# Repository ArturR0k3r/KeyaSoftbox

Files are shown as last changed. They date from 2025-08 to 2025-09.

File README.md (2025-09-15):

# KSB (Keya-Soft-Box) - Mesh LED Lighting System




[]()

A self-organizing mesh network LED lighting system built on ESP32 microcontrollers running Zephyr RTOS. KSB enables multiple LED lamps to automatically discover and connect to each other, creating synchronized lighting effects across an entire network.

KSB Hardware

## 🌟 Features

- **🔗 Automatic Mesh Networking**: Devices self-discover and form mesh networks
- **🎨 Synchronized LED Control**: Coordinated lighting effects across all connected devices
- **📱 Web Configuration**: Simple browser-based setup interface
- **🔋 Battery Monitoring**: Built-in power management and monitoring
- **🛡️ Self-Healing Network**: Automatic recovery from node failures  
- **⚡ Real-time RTOS**: Built on Zephyr RTOS for reliable operation
- **🎯 Multiple Board Support**: ESP32-S3, ESP32-C3, and XIAO variants

## 🚀 Quick Start

### Prerequisites

1. **Install Zephyr SDK**:
   ```bash
   cd your-workspace
   west init -m https://github.com/zephyrproject-rtos/zephyr --mr v3.4.0
   west update
   west blobs fetch hal_espressif
   ```

2. **Install ESP Tool**:
   ```bash
   pip3 install --user --upgrade esptool>=5.0.2 --break-system-packages
   export PATH=$HOME/.local/bin:$PATH
   ```

### Clone & Build

```bash
git clone https://github.com/your-org/keya-soft-box.git
cd keya-soft-box

# Build for ESP32-S3-DevKitM (default)
west build -b esp32s3_devkitm

# Or build for other supported boards:
# west build -b esp32c3_devkitm
# west build -b xiao_esp32c3

# Flash the firmware
west flash

# Monitor serial output
west build -t monitor
```

## 🔌 Hardware

### Supported Boards
- **ESP32-S3-DevKitM** - Primary development platform
### Soon Will Be
- **ESP32-C3-DevKitM** - Compact alternative
- **XIAO ESP32C3** - Ultra-small form factor

### Hardware Features
- **ESP32-S3/C3** microcontroller with WiFi
- **8x WS2812B** addressable LEDs
- **User button** with debouncing
- **Dual status LEDs** (Red/Green)
- **Battery monitoring** via ADC
- **Debug interface** (UART + SWD)
- **Power regulation** and filtering

### Pin Configuration
```
LED Strip:    GPIO11 (SPI2 MOSI) 
User Button:  GPIO0 (Pull-up, Active Low)
Status LEDs:  Red/Green with 220Ω resistors
Debug UART:   TX=GPIO43, RX=GPIO44
Power:        3.3V regulated with monitoring
```

## 📊 System Architecture

### Mesh Network States
```mermaid
stateDiagram-v2
    [*] --> SYSTEM_INIT
    SYSTEM_INIT --> CONFIG_MODE : Hardware Ready
    CONFIG_MODE --> NETWORK_SCAN : User Config Done
    NETWORK_SCAN --> MESH_CLIENT : Network Found
    NETWORK_SCAN --> MESH_MASTER : No Network Found
    MESH_CLIENT --> OPERATIONAL : Connected to Mesh
    MESH_MASTER --> OPERATIONAL : Mesh Created
    OPERATIONAL --> CONNECTION_LOST : Network Failure
    CONNECTION_LOST --> ERROR_RECOVERY : Start Recovery
    ERROR_RECOVERY --> CONFIG_MODE : Recovery Failed
    ERROR_RECOVERY --> NETWORK_SCAN : Retry Connection
```

### Key Components
- **Mesh Networking**: Self-organizing WiFi mesh with automatic node discovery
- **LED Control**: Synchronized WS2812B patterns across all network nodes  
- **Web Interface**: Browser-based configuration at `192.168.4.1` during setup
- **State Machine**: Robust state management with error recovery
- **NVS Storage**: Persistent configuration storage

## ⚙️ Configuration

### Device Tree Setup
The project includes board-specific overlays:

```c
// WS2812B LED strip configuration
&spi2 {
    led_strip: ws2812@0 {
        compatible = "worldsemi,ws2812-spi";
        chain-length = <8>;
        spi-max-frequency = <4000000>;
        color-mapping = <LED_COLOR_ID_GREEN>,
                        <LED_COLOR_ID_RED>, 
                        <LED_COLOR_ID_BLUE>;
    };
};
```

### Kconfig Options
Key configuration options in `prj.conf`:
```
CONFIG_WS2812B_STRIP=y
CONFIG_WS2812B_MAX_PIXELS=256
CONFIG_NETWORKING=y
CONFIG_WIFI=y
CONFIG_HTTP_SERVER=y
CONFIG_NVS=y
```

## 🎮 Usage

### Initial Setup
1. **Power on** the device - it creates a WiFi access point `KSB_Setup_XXXX`
2. **Connect** to the AP and navigate to `192.168.4.1`
3. **Configure** your mesh network name (e.g., "Living Room")
4. **Save** configuration - device will restart and search for existing networks

### Network Formation
- **First device**: Creates new mesh network as root node
- **Additional devices**: Automatically discover and join existing mesh
- **Status indication**: LEDs show current state (scanning, connecting, operational)

### LED Control
- **Synchronized patterns** across all connected devices
- **Button control** for basic pattern switching
- **Web interface** for advanced pattern configuration
- **Mesh broadcast** ensures all nodes stay synchronized

## 🛠️ Development

### Project Structure
```
keya-soft-box/
├── boards/                 # Board-specific overlays
├── dts/                    # Device tree sources
├── Housing/                # Housing 3d models for print 
├── include/                # Version include
├── modules/                # modules.cmake
├── src/                    # Application source
│   ├── main.c             # Main application
│   ├── mesh_network.c     # Mesh networking logic
│   ├── led_control.c      # LED pattern control
│   └── web_config.c       # Web configuration
├── Wiring/                 # Schematic for KSB
├── ws2812/                 # WS2812 custom driver 
├── CMakeLists.txt          # Build configuration
├── Kconfig                 # Config options
├── KSB.code-workspace      # VS-code workspace
├── LICENSE                 # License file
├── prj.conf                # Project config
├── README.md               # this doc
└── west.yml                # file for west update
```

### Building for Different Boards

```bash
# ESP32-S3-DevKitM (recommended)
west build -b esp32s3_devkitm

# ESP32-C3-DevKitM  
west build -b esp32c3_devkitm

# XIAO ESP32C3
west build -b xiao_esp32c3
```

### Custom LED Patterns
Add new patterns in `src/led_control.c`:
```c
void pattern_custom(struct led_rgb *leds, uint32_t frame) {
    // Your custom pattern implementation
    for (int i = 0; i < LED_STRIP_LENGTH; i++) {
        leds[i] = (struct led_rgb){
            .r = /* red value */,
            .g = /* green value */,
            .b = /* blue value */
        };
    }
}
```

## 🧪 Testing

### Hardware Testing
- [ ] Power supply regulation (3.3V ±5%)
- [ ] All 8 WS2812B LEDs functional
- [ ] Button input with proper debouncing
- [ ] UART debug communication
- [ ] WiFi connectivity and range

### Software Testing  
- [ ] State machine transitions
- [ ] Mesh network formation (2-8 nodes)
- [ ] LED pattern synchronization
- [ ] Network recovery after node failure
- [ ] Configuration persistence

### Performance Targets
- **Mesh formation**: < 60 seconds for 8 nodes
- **LED update rate**: 30 FPS
- **Network recovery**: < 10 seconds  
- **Power consumption**: < 500mA @ 3.3V per node
- **Range**: 10-30m indoor, 50-100m outdoor

## 🐛 Troubleshooting

### Common Issues

**Build Errors**
```bash
# Ensure Zephyr SDK is properly installed
west --version
which esptool.py

# Clean and rebuild
west build -t clean
west build
```

**Flash Errors**
```bash
# Check USB connection and permissions
ls -la /dev/ttyUSB* /dev/ttyACM*

# Try different baud rate
west flash --baud 115200
```

**WiFi Connection Issues**
- Check antenna connection
- Verify 2.4GHz WiFi support
- Ensure regulatory domain settings
- Test in different locations for interference

**LED Problems**  
- Verify 3.3V power supply stability
- Check WS2812B data line continuity
- Ensure proper GND connection
- Test with simple solid color first

### Debug Output
Enable detailed logging in `prj.conf`:
```
CONFIG_LOG=y
CONFIG_LOG_DEFAULT_LEVEL=4
CONFIG_MESH_NETWORK_LOG_LEVEL_DBG=y
```

## 📚 API Documentation

### Mesh Network API
```c
// Initialize mesh networking
int mesh_network_init(const char *network_name);

// Join or create mesh network
int mesh_network_start(void);

// Send LED command to all nodes
int mesh_broadcast_led_command(struct led_command *cmd);
```

### LED Control API
```c
// Set LED pattern for entire strip
int led_set_pattern(enum led_pattern pattern, struct led_rgb color);

// Update single LED
int led_set_pixel(int index, struct led_rgb color);

// Apply changes to physical LEDs
int led_update_strip(void);
```

## 🤝 Contributing

We welcome contributions! Please see our [Contributing Guide](CONTRIBUTING.md) for details.

### Development Workflow
1. **Fork** the repository
2. **Create** a feature branch (`git checkout -b feature/amazing-feature`)
3. **Commit** your changes (`git commit -m 'Add amazing feature'`)
4. **Push** to the branch (`git push origin feature/amazing-feature`)
5. **Open** a Pull Request

### Code Style
- Follow Zephyr coding conventions
- Use descriptive variable and function names
- Add comments for complex algorithms
- Include unit tests for new features

## 📋 Versions

### Version 1.1 (Done)
- [ ] Web interface for remote control
- [ ] Advanced LED patterns and effects
- [ ] Energy-saving sleep modes
- [ ] Over-the-air (OTA) firmware updates

## 📄 License

This project is licensed under the MIT License - see the [LICENSE](LICENSE) file for details.

## 🙏 Acknowledgments

- **Zephyr Project** - For the excellent RTOS foundation
- **Espressif** - For ESP32 hardware and support
- **WS2812B Community** - For LED strip driver inspiration
- **Contributors** - Everyone who helps improve this project

## 📞 Support

- **Issues**: Report bugs and request features on [GitHub Issues](https://github.com/ArturR0k3r/KeyaSoftbox/issues)
- **Email**: Contact the maintainers at artur@pen.engineering

---

**⭐ Star this repo if you find it useful!**

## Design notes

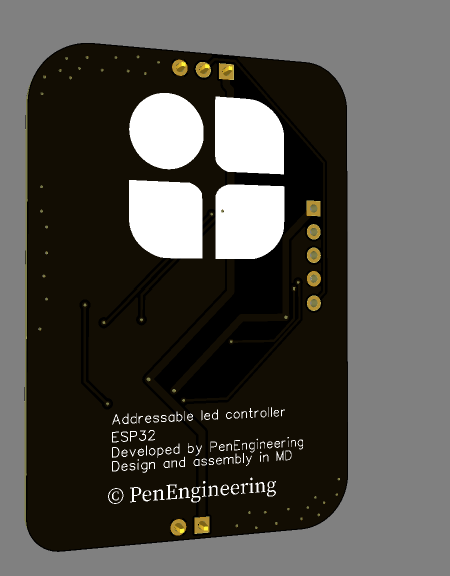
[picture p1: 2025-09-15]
Hardware/Screenshot 2025-09-14 190648.png

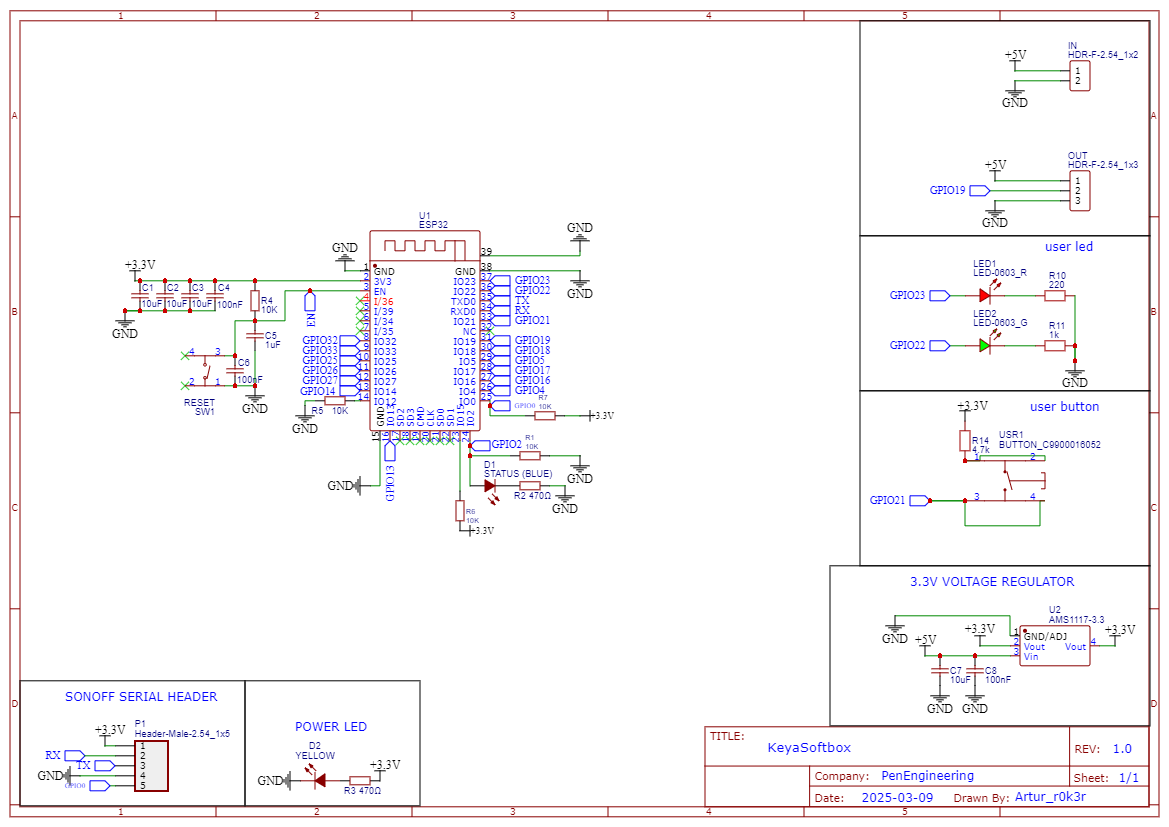
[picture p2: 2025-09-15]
Hardware/Schematic_KeyaSoftbox_2025-09-14.png

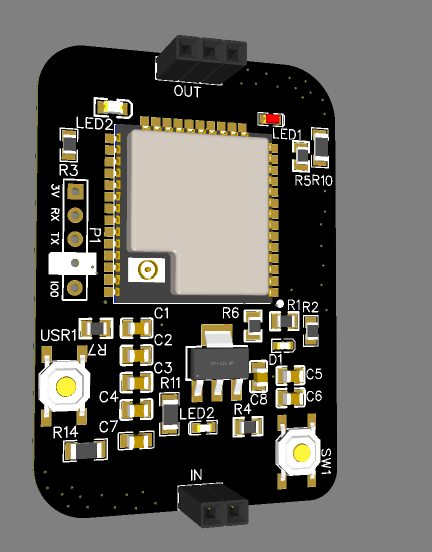
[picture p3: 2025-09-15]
Hardware/Screenshot 2025-09-14 190716.png

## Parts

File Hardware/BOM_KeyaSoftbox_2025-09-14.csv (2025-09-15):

ID | Name | Designator | Footprint | Quantity | Manufacturer Part | Manufacturer | Supplier | Supplier Part | Price
1 | YELLOW | D2 | LED0805-RD | 1 | 17-21SUYC/TR8 | KENTO | LCSC | C2296 | 0.012
2 | LED-0603_G | LED2 | LED0603_GREEN | 1 | 19-217/GHC-YR1S2/3T | EVERLIGHT(台湾亿光) | LCSC | C72043 | 0.022
3 | STATUS (BLUE) | D1 | LED0603-R-RD | 1 | 19-217/BHC-ZL1M2RY/3T | EVERLIGHT | LCSC | C72041 | 0.023
4 | LED-0603_R | LED1 | LED0603_RED | 1 | 19-217/R6C-AL1M2VY/3T | EVERLIGHT(台湾亿光) | LCSC | C72044 | 0.021
5 | 10uF | C1,C2,C3,C7 | C0805 | 4 | CL21A106KAYNNNE | SAMSUNG | LCSC | C15850 | 0.011
6 | 100nF | C4,C6,C8 | C0805 | 3 | CC0805KRX7R9BB104 | YAGEO | LCSC | C49678 | 0.005
7 | 1uF | C5 | C0805 | 1 | CL21B105KBFNNNE | SAMSUNG | LCSC | C28323 | 0.009
8 | HDR-F-2.54_1x2 | IN | HDR-F-2.54_1X2 | 1 |  |  | LCSC | C49661 | 0.038
9 | HDR-F-2.54_1x3 | OUT | HDR-F-2.54_1X3 | 1 |  |  | LCSC | C146690 | 0.087
10 | Header-Male-2.54_1x5 | P1 | HDR-5X1/2.54 | 1 | Header-Male-2.54_1x5 | LCSC
11 | 10K | R1,R4,R5,R6,R7 | R0805 | 5 | 0805W8F1002T5E | UniOhm | LCSC | C17414 | 0.002
12 | 470Ω | R2,R3 | R0805 | 2 | 0805W8F4700T5E | UniOhm | LCSC | C17710 | 0.002
13 | 220 | R10 | R1206 | 1
14 | 1k | R11 | R1206 | 1
15 | 4.7k | R14 | R1206 | 1
16 | RESET | SW1 | SW-SMD_4P-L5.1-W5.1-P3.70-LS6.5-TL-2 | 1 | TS-1187A-B-A-B | XKB Enterprise | LCSC | C318884 | 0.019
17 | ESP32 | U1 | WIFIM-SMD_38P-L19.2-W18.0-P1.27 | 1 | ESP32 |  | LCSC | C328062 | 3.523
18 | AMS1117-3.3 | U2 | SOT-223-3_L6.5-W3.4-P2.30-LS7.0-BR | 1 | AMS1117-3.3 | AMS | LCSC | C6186 | 0.167
19 | BUTTON_C9900016052 | USR1 | SW-SMD_4P-L5.1-W5.1-P3.70-LS6.5-TL-2 | 1 | button | null | LCSC | C9900016052

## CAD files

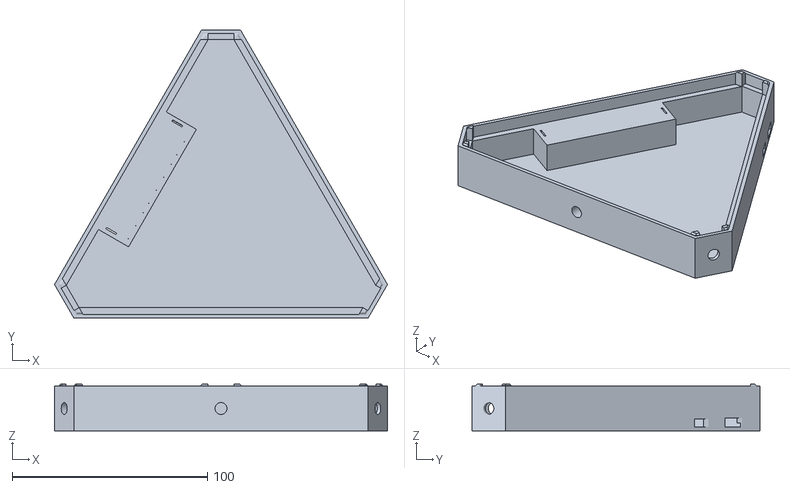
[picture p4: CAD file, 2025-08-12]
Housing/KSB_Body.stl
170.6 x 147.7 x 24.0

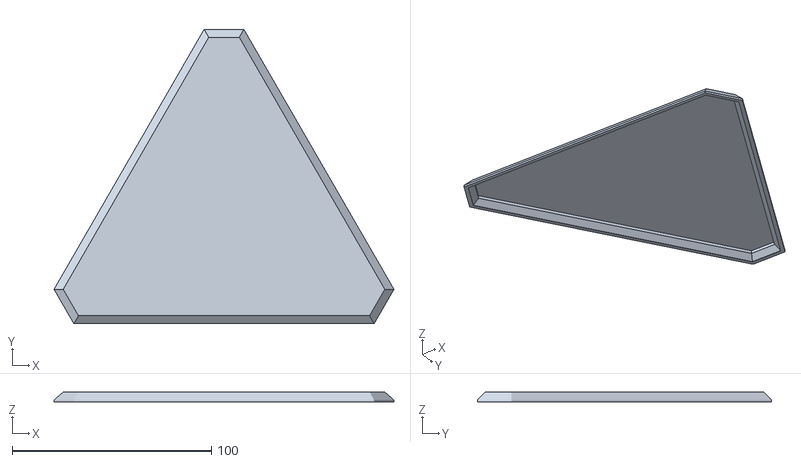
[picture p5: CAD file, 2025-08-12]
Housing/KSB_Top.stl
170.6 x 147.7 x 5.00

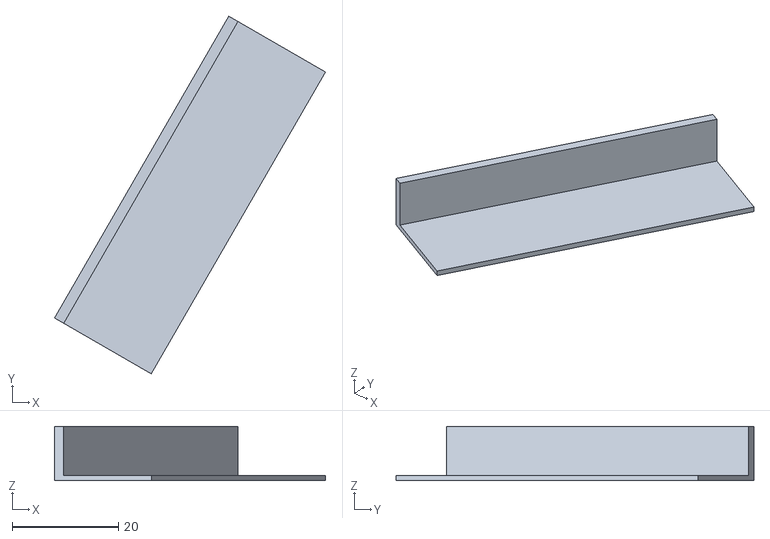
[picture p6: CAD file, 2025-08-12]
Housing/KSB_BatLid.stl
50.9 x 67.2 x 10.2

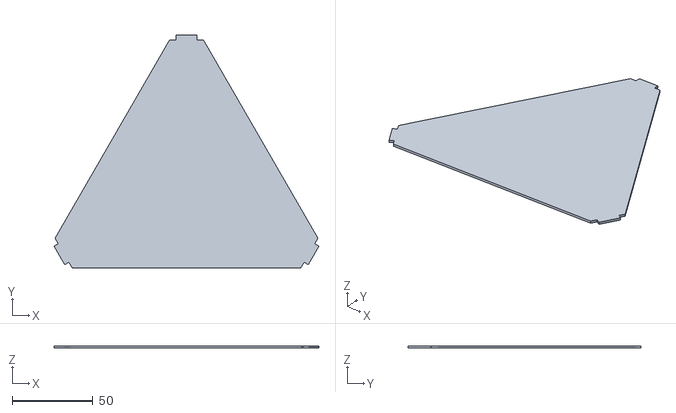
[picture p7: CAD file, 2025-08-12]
Housing/KSB_LED_Holder.stl
163.8 x 143.7 x 1.40

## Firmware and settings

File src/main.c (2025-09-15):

#include <zephyr/kernel.h>
#include <zephyr/device.h>
#include <zephyr/drivers/gpio.h>
#include <zephyr/logging/log.h>
#include <zephyr/random/random.h>

#include "ksb_common.h"
#include "state_machine.h"
#include "nvs_storage.h"
#include "../ws2812/ws2812_driver.h"

LOG_MODULE_REGISTER(main, CONFIG_LOG_DEFAULT_LEVEL);

// Global system context
struct ksb_context g_ksb_ctx = {
    .current_state = KSB_STATE_SYSTEM_INIT,
    .system_running = true};

// Hardware devices
static const struct device *button_dev;
static const struct device *status_red_dev;
static const struct device *status_green_dev;
static const struct device *gpio_dev;
static struct gpio_callback button_cb_data;

// Button handler
static void button_pressed(const struct device *dev, struct gpio_callback *cb, uint32_t pins)
{
    LOG_INF("User button pressed");
    // Cycle through LED patterns in operational mode
    if (g_ksb_ctx.current_state == KSB_STATE_OPERATIONAL)
    {
        led_control_next_pattern();
    }
}

// Status LED control
static void set_status_leds(bool red, bool green)
{
    if (gpio_dev)
    {
        gpio_pin_set(gpio_dev, 23, red ? 1 : 0);   // user_led1
        gpio_pin_set(gpio_dev, 22, green ? 1 : 0); // user_led2
    }
}

// Status LED thread
static void status_led_thread(void)
{
    while (g_ksb_ctx.system_running)
    {
        switch (g_ksb_ctx.current_state)
        {
        case KSB_STATE_SYSTEM_INIT:
            // Fast red blink during init
            set_status_leds(true, false);
            k_msleep(100);
            set_status_leds(false, false);
            k_msleep(100);
            break;

        case KSB_STATE_CONFIG_MODE:
            // Alternating red/green in config mode
            set_status_leds(true, false);
            k_msleep(500);
            set_status_leds(false, true);
            k_msleep(500);
            break;

        case KSB_STATE_NETWORK_SCAN:
        case KSB_STATE_MESH_CLIENT:
        case KSB_STATE_MESH_MASTER:
            // Slow green blink during connection
            set_status_leds(false, true);
            k_msleep(250);
            set_status_leds(false, false);
            k_msleep(1750);
            break;

        case KSB_STATE_OPERATIONAL:
            // Solid green when operational
            set_status_leds(false, true);
            k_msleep(1000);
            break;

        case KSB_STATE_CONNECTION_LOST:
        case KSB_STATE_ERROR_RECOVERY:
            // Fast red blink on error
            set_status_leds(true, false);
            k_msleep(200);
            set_status_leds(false, false);
            k_msleep(200);
            break;

        default:
            set_status_leds(false, false);
            k_msleep(1000);
            break;
        }
    }
}

K_THREAD_DEFINE(status_led_tid, 1024, status_led_thread, NULL, NULL, NULL, 7, 0, 0);

// Hardware initialization
static int init_hardware(void)
{
    int ret;

    // Get GPIO device for button and LEDs
    gpio_dev = DEVICE_DT_GET(DT_NODELABEL(gpio0));
    if (!device_is_ready(gpio_dev))
    {
        LOG_ERR("GPIO device not ready");
        return -ENODEV;
    }

    // Configure button pin
    ret = gpio_pin_configure(gpio_dev, 21, GPIO_INPUT | GPIO_PULL_UP);
    if (ret != 0)
    {
        LOG_ERR("Failed to configure button pin");
        return ret;
    }

    ret = gpio_pin_interrupt_configure(gpio_dev, 21, GPIO_INT_EDGE_TO_ACTIVE);
    if (ret != 0)
    {
        LOG_ERR("Failed to configure button interrupt");
        return ret;
    }

    gpio_init_callback(&button_cb_data, button_pressed, BIT(21));
    gpio_add_callback(gpio_dev, &button_cb_data);

    // Configure status LED pins
    ret = gpio_pin_configure(gpio_dev, 23, GPIO_OUTPUT_INACTIVE); // user_led1
    if (ret != 0)
    {
        LOG_ERR("Failed to configure red LED pin");
        return ret;
    }
    ret = gpio_pin_configure(gpio_dev, 22, GPIO_OUTPUT_INACTIVE); // user_led2
    if (ret != 0)
    {
        LOG_ERR("Failed to configure green LED pin");
        return ret;
    }

    LOG_INF("Hardware initialized successfully");
    return 0;
}

int main(void)
{
    int ret;

    LOG_INF("KSB v%s starting...", KSB_VERSION_STRING);
    LOG_INF("Build: %s %s", KSB_BUILD_DATE, KSB_BUILD_TIME);

    // Initialize semaphores
    k_sem_init(&g_ksb_ctx.state_lock, 1, 1);

    // Initialize NVS storage
    ret = nvs_storage_init();
    if (ret != 0)
    {
        LOG_ERR("Failed to initialize NVS storage: %d", ret);
        return ret;
    }

    // Load configuration
    ret = nvs_storage_load_config(&g_ksb_ctx.config);
    if (ret != 0)
    {
        LOG_WRN("No valid configuration found, using defaults");
        memset(&g_ksb_ctx.config, 0, sizeof(g_ksb_ctx.config));
        g_ksb_ctx.config.is_configured = false;
        g_ksb_ctx.config.device_id = sys_rand32_get() & 0xFF;
    }

    // Initialize hardware
    ret = init_hardware();
    if (ret != 0)
    {
        LOG_ERR("Hardware initialization failed: %d", ret);
        return ret;
    }

    // Initialize LED control
    ret = led_control_init();
    if (ret != 0)
    {
        LOG_ERR("LED control initialization failed: %d", ret);
        return ret;
    }

    // Show startup pattern
    struct led_rgb startup_color = {50, 0, 50}; // Purple
    led_control_set_pattern(KSB_PATTERN_SOLID, startup_color, 255, 0);
    k_msleep(1000);
    led_control_set_pattern(KSB_PATTERN_OFF, (struct led_rgb){0, 0, 0}, 0, 0);

    // Initialize state machine
    ret = state_machine_init();
    if (ret != 0)
    {
        LOG_ERR("State machine initialization failed: %d", ret);
        return ret;
    }

    LOG_INF("KSB initialization complete");

    // Start state machine
    state_machine_start();

    return 0;
}

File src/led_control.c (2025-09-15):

#include <zephyr/kernel.h>
#include <zephyr/logging/log.h>
#include <zephyr/random/random.h>

#include <math.h>
#include "ksb_common.h"
#include "led_control.h"
#include "mesh_network.h"
#include "../ws2812/ws2812_driver.h"

LOG_MODULE_REGISTER(led_control, CONFIG_LOG_DEFAULT_LEVEL);

static struct led_control_context
{
    struct ws2812_driver ws_driver;
    enum ksb_led_pattern current_pattern;
    struct led_rgb current_color;
    uint32_t current_brightness;
    uint32_t current_speed;
    uint32_t frame_counter;
    bool running;
    struct k_thread led_thread;
    K_KERNEL_STACK_MEMBER(led_stack, 2048);
} led_ctx;

// Pattern implementations
static void pattern_off(struct led_rgb *leds, uint32_t frame)
{
    struct led_rgb black = {0, 0, 0};
    for (int i = 0; i < KSB_LED_COUNT; i++)
    {
        leds[i] = black;
    }
}

static void pattern_solid(struct led_rgb *leds, uint32_t frame)
{
    for (int i = 0; i < KSB_LED_COUNT; i++)
    {
        leds[i] = led_ctx.current_color;
    }
}

static void pattern_breathing(struct led_rgb *leds, uint32_t frame)
{
    // Sine wave breathing effect
    float breath = (sin((frame * led_ctx.current_speed) / 1000.0f) + 1.0f) / 2.0f;
    uint8_t brightness = (uint8_t)(breath * led_ctx.current_brightness);

    struct led_rgb color = {
        (led_ctx.current_color.r * brightness) / 255,
        (led_ctx.current_color.g * brightness) / 255,
        (led_ctx.current_color.b * brightness) / 255};

    for (int i = 0; i < KSB_LED_COUNT; i++)
    {
        leds[i] = color;
    }
}

static void pattern_running_light(struct led_rgb *leds, uint32_t frame)
{
    // Clear all LEDs
    struct led_rgb black = {0, 0, 0};
    for (int i = 0; i < KSB_LED_COUNT; i++)
    {
        leds[i] = black;
    }

    // Calculate position
    int pos = (frame * led_ctx.current_speed / 100) % KSB_LED_COUNT;
    leds[pos] = led_ctx.current_color;

    // Add trail
    int trail_pos = (pos - 1 + KSB_LED_COUNT) % KSB_LED_COUNT;
    leds[trail_pos] = (struct led_rgb){
        led_ctx.current_color.r / 3,
        led_ctx.current_color.g / 3,
        led_ctx.current_color.b / 3};
}

static void pattern_rainbow(struct led_rgb *leds, uint32_t frame)
{
    for (int i = 0; i < KSB_LED_COUNT; i++)
    {
        float hue = ((frame * led_ctx.current_speed / 10) + (i * 360 / KSB_LED_COUNT)) % 360;

        // Simple HSV to RGB conversion
        float c = (float)led_ctx.current_brightness / 255.0f;
        float x = c * (1 - fabs(fmod(hue / 60.0f, 2) - 1));
        float m = 0;

        float r, g, b;
        if (hue < 60)
        {
            r = c;
            g = x;
            b = 0;
        }
        else if (hue < 120)
        {
            r = x;
            g = c;
            b = 0;
        }
        else if (hue < 180)
        {
            r = 0;
            g = c;
            b = x;
        }
        else if (hue < 240)
        {
            r = 0;
            g = x;
            b = c;
        }
        else if (hue < 300)
        {
            r = x;
            g = 0;
            b = c;
        }
        else
        {
            r = c;
            g = 0;
            b = x;
        }

        leds[i] = (struct led_rgb){
            (uint8_t)((r + m) * 255),
            (uint8_t)((g + m) * 255),
            (uint8_t)((b + m) * 255)};
    }
}

static void pattern_sparkle(struct led_rgb *leds, uint32_t frame)
{
    // Start with dim background
    struct led_rgb dim_color = {
        led_ctx.current_color.r / 10,
        led_ctx.current_color.g / 10,
        led_ctx.current_color.b / 10};

    for (int i = 0; i < KSB_LED_COUNT; i++)
    {
        leds[i] = dim_color;
    }

    // Add random sparkles
    if ((frame % (200 - led_ctx.current_speed)) == 0)
    {
        int sparkle_pos = sys_rand32_get() % KSB_LED_COUNT;
        leds[sparkle_pos] = led_ctx.current_color;
    }
}

static void pattern_wave(struct led_rgb *leds, uint32_t frame)
{
    for (int i = 0; i < KSB_LED_COUNT; i++)
    {
        float wave = sin((frame * led_ctx.current_speed / 100.0f) + (i * 3.14159f / KSB_LED_COUNT));
        wave = (wave + 1.0f) / 2.0f; // Normalize to 0-1

        uint8_t brightness = (uint8_t)(wave * led_ctx.current_brightness);

        leds[i] = (struct led_rgb){
            (led_ctx.current_color.r * brightness) / 255,
            (led_ctx.current_color.g * brightness) / 255,
            (led_ctx.current_color.b * brightness) / 255};
    }
}

// LED control thread
static void led_control_thread(void *arg1, void *arg2, void *arg3)
{
    struct led_rgb leds[KSB_LED_COUNT];

    while (led_ctx.running)
    {
        // Apply brightness scaling
        uint8_t brightness_scale = led_ctx.current_brightness;

        // Generate pattern
        switch (led_ctx.current_pattern)
        {
        case KSB_PATTERN_OFF:
            pattern_off(leds, led_ctx.frame_counter);
            break;
        case KSB_PATTERN_SOLID:
            pattern_solid(leds, led_ctx.frame_counter);
            break;
        case KSB_PATTERN_BREATHING:
            pattern_breathing(leds, led_ctx.frame_counter);
            break;
        case KSB_PATTERN_RUNNING_LIGHT:
            pattern_running_light(leds, led_ctx.frame_counter);
            break;
        case KSB_PATTERN_RAINBOW:
            pattern_rainbow(leds, led_ctx.frame_counter);
            break;
        case KSB_PATTERN_SPARKLE:
            pattern_sparkle(leds, led_ctx.frame_counter);
            break;
        case KSB_PATTERN_WAVE:
            pattern_wave(leds, led_ctx.frame_counter);
            break;
        default:
            pattern_off(leds, led_ctx.frame_counter);
            break;
        }

        // Apply global brightness scaling (except for breathing which handles its own)
        if (led_ctx.current_pattern != KSB_PATTERN_BREATHING)
        {
            for (int i = 0; i < KSB_LED_COUNT; i++)
            {
                leds[i].r = (leds[i].r * brightness_scale) / 255;
                leds[i].g = (leds[i].g * brightness_scale) / 255;
                leds[i].b = (leds[i].b * brightness_scale) / 255;
            }
        }

        // Update physical LEDs
        for (int i = 0; i < KSB_LED_COUNT; i++)
        {
            led_ctx.ws_driver.pixels[i] = leds[i];
        }
        led_strip_update_rgb(led_ctx.ws_driver.dev, led_ctx.ws_driver.pixels, KSB_LED_COUNT);

        led_ctx.frame_counter++;
        k_msleep(KSB_LED_UPDATE_RATE_MS);
    }
}
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

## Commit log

2025-03-06 Updated 3dModels arduinoSketch and wiring diagram
    [Body.stl, Diffusor.stl, Ledholder.stl]
2025-03-07 fixed 3dModels
    [Body.stl]
2025-03-09 Update Sketch added smaller version and Better Wiring Diagram
    [BodySmall60%size.stl]
2025-08-12 v2 Init
    [Body.stl, BodySmall60%size.stl, Diffusor.stl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]
2025-08-12 added wiring and housing
    [KSB_BatLid.stl, KSB_Body.stl, KSB_LED_Holder.stl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]
2025-08-14 update for esp32 boards and readme
2025-08-19 added custom driver for WS2812
2025-09-15 Updated to V1.1 to be tested on full HW build
    [BOM_KeyaSoftbox_2025-09-14.csv, PickAndPlace_PCB_KeyaSoftbox_2025-09-14.csv]

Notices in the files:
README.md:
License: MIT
